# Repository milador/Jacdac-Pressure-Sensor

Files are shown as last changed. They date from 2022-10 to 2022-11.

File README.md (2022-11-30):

# Jacdac-Pressure-Sensor
A <a href="https://microsoft.github.io/jacdac-docs/">Jacdac</a> Pressure Sensor Module based on <a href="https://www.st.com/en/mems-and-sensors/lps33hw.html">LPS33HW</a> Absolute digital Pressure Sensor.

## Jacdac Dashboard: 

<p align="center">
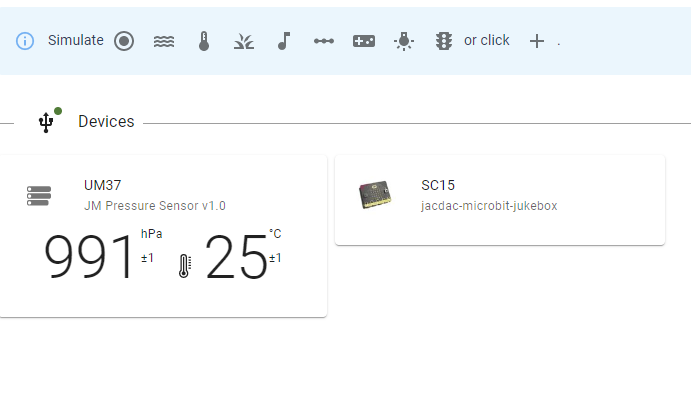
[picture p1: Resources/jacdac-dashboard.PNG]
Jacdac-Pressure-Sensor dashboard example

</p>

## Top View: 

<p align="center">
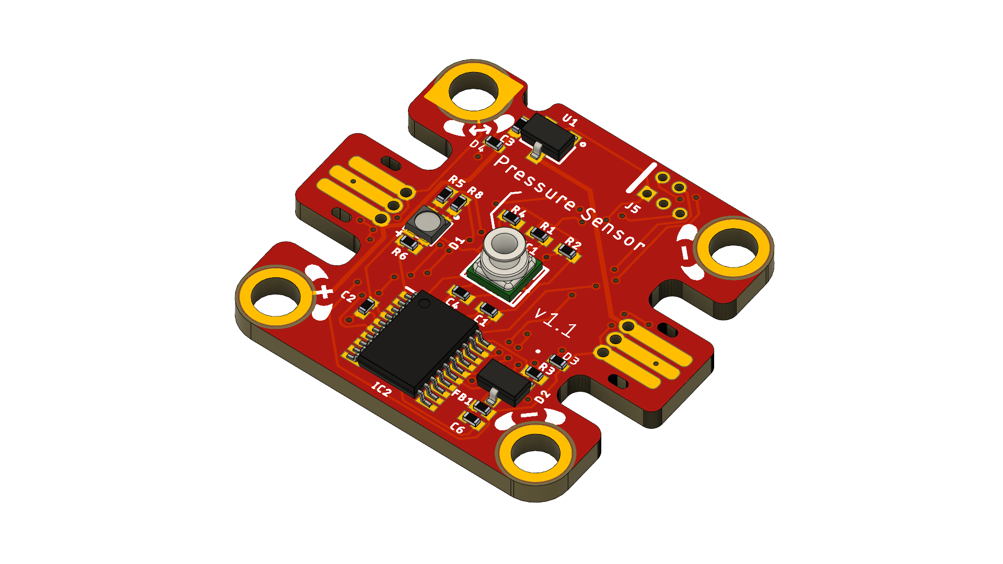
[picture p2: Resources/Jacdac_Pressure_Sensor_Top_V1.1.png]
Jacdac-Pressure-Sensor Top

</p>

## Bottom View:

<p align="center">
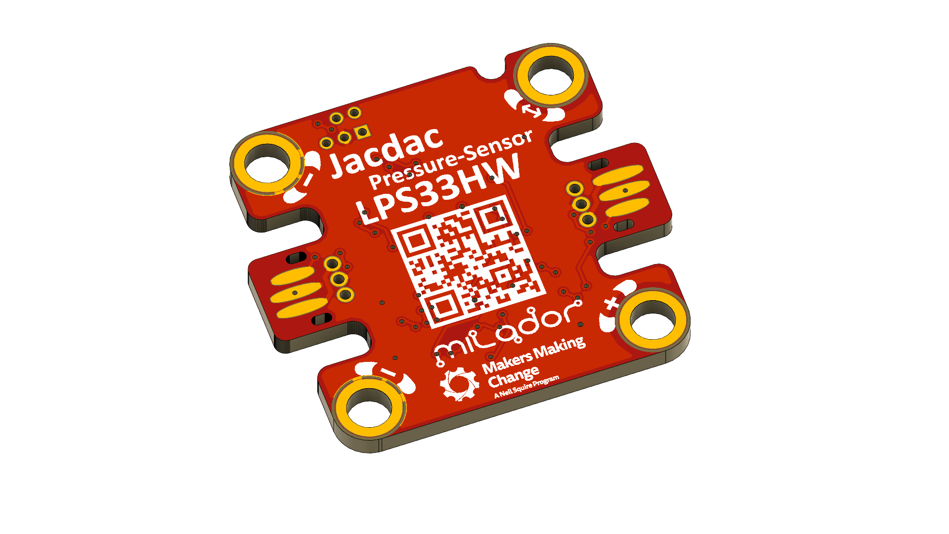
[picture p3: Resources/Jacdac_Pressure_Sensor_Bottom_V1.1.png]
Jacdac-Pressure-Sensor Bottom

</p>

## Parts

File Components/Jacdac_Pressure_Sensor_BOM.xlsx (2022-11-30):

Index | Quantity | Item | Value | Part Number | Manufacturer Part Number | Description | Unit Price (CAD) | Total Price (CAD) | Link
1 | 3 | R1,R2,R4 | 10K | C2902636 | ARG02BTC1002 | RES 10K OHM 0.1% 0402 | 0.0233 | 0.0699 | https://lcsc.com/product-detail/Chip-Resistor-Surface-Mount_Viking-Tech-ARG02BTC1002_C2902636.html
2 | 2 | R3,R5 | 220R | C317911 | AR02BTC2200 | RES 220 OHM 0.1% 0402 | 0.0272 | 0.0544 | https://lcsc.com/product-detail/Chip-Resistor-Surface-Mount_Viking-Tech-AR02BTC2200_C317911.html
3 | 1 | R6 | 470R | C482182 | CRCW0402470RFKED | RES 470 OHM 1% 0402 | 0.0394 | 0.0394 | https://lcsc.com/product-detail/Chip-Resistor-Surface-Mount_Vishay-Intertech-CRCW0402470RFKED_C482182.html
4 | 1 | R8 | 150R | C319855 | AR02BTC1500 | RES 150 OHM 0.1% 0402 | 0.032 | 0.032 | https://lcsc.com/product-detail/Chip-Resistor-Surface-Mount_Viking-Tech-AR02BTC1500_C319855.html
5 | 1 | IC1 | LPS33HWTR | C2760770 | LPS33HWTR | PRESSURE SENSOR | 10.89 | 10.89 | https://www.digikey.ca/en/products/detail/stmicroelectronics/LPS33HWTR/7348329 | https://lcsc.com/product-detail/Magnetic-Sensors_Infineon-Technologies-TLV493DA1B6HTSA2_C126688.html
6 | 1 | IC2 | STM32G030F6P6 | C724040 | STM32G030F6P6 | IC MCU 32BIT 32KB FLASH 20TSSOP | 0.98 | 0.98 | https://lcsc.com/product-detail/ST-Microelectronics_STMicroelectronics-STM32G030F6P6_C724040.html
7 | 1 | U1 | XC6206-3.3V | C2891841 | XC6206-3.3V | IC REG LINEAR 3.3V SOT-23-3L | 0.0614 | 0.0614 | https://lcsc.com/product-detail/Linear-Voltage-Regulators-LDO_YONGYUTAI-XC6206-3-3V_C2891841.html
8 | 2 | C1,C4 | 100nF | C361202 | C1005X5R1H104KT000F | 50V 100nF X5R ±10% 0402 | 0.0227 | 0.0454 | https://lcsc.com/product-detail/Multilayer-Ceramic-Capacitors-MLCC-SMD-SMT_TDK-C1005X5R1H104KT000F_C361202.html
9 | 2 | C2,C3 | 4.7uF | C342983 | C1005X5R1A475KTJ00E | 10V 4.7uF X5R ±10% 0402 | 0.0476 | 0.0952 | https://lcsc.com/product-detail/Multilayer-Ceramic-Capacitors-MLCC-SMD-SMT_TDK-C1005X5R1A475KTJ00E_C342983.html
10 | 1 | C6 | 33pF | C76905 | GJM1555C1H330GB01D | 50V 33pF C0G ±2% 0402 | 0.0335 | 0.0335 | https://lcsc.com/product-detail/Multilayer-Ceramic-Capacitors-MLCC-SMD-SMT_Murata-Electronics-GJM1555C1H330GB01D_C76905.html
11 | 1 | FB1 | 1kΩ @ 100MHz | C275423 | MMZ1005S102ET000 | FERRITE BEAD 250mA 1 1Ω 1kΩ@100MHz ±25% 0402 | 0.0308 | 0.0308 | https://lcsc.com/product-detail/Ferrite-Beads_TDK-MMZ1005S102ET000_C275423.html
12 | 1 | D1 | RGB LED | C108793 | FM-B2020RGBA-HG | LED RGB CHIP SMD | 0.0289 | 0.0289 | https://lcsc.com/product-detail/Light-Emitting-Diodes-LED_Foshan-NationStar-Optoelectronics-FM-B2020RGBA-HG_C108793.html
13 | 1 | D2 | BAT54S | C328578 | BAT54S,23 | DIODE ARRAY SCHOTTKY 30V SOT23 | 0.0245 | 0.0245 | https://lcsc.com/product-detail/Schottky-Barrier-Diodes-SBD_Foshan-Blue-Rocket-Elec-BAT54S_C328578.html
14 | 2 | D3,D4 | RCLAMP0521P | C2827711 | RCLAMP0521P | TVS DIODE 5VWM 25VC SLP1006P2 | 0.0445 | 0.089 | https://lcsc.com/product-detail/ESD-Protection-Devices_TECH-PUBLIC-RCLAMP0521P_C2827711.html
 |  |  |  |  |  |  | Total Price: | 12.4744

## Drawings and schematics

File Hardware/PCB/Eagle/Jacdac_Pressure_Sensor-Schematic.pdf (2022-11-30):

# 1k@100MHz VCC

# JD5V VCC

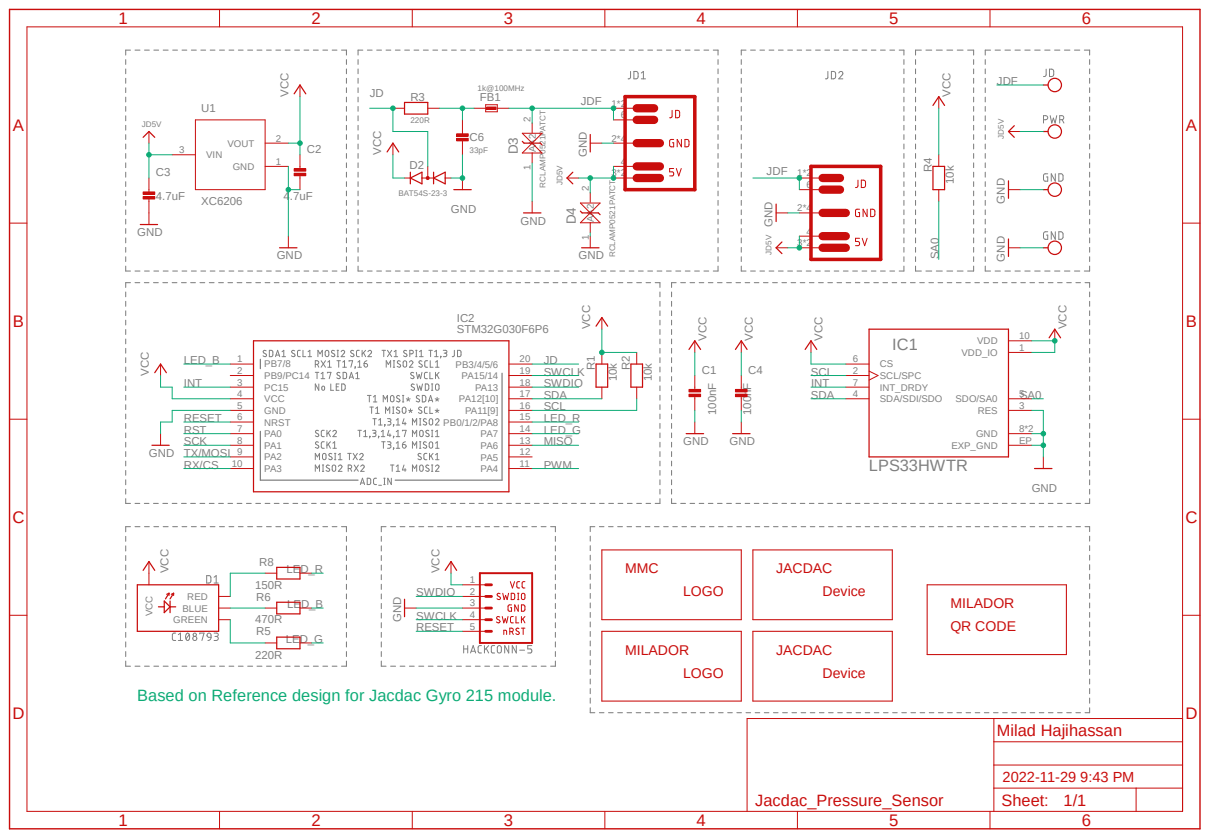
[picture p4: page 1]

Based on Reference design for Jacdac Gyro 215 module.

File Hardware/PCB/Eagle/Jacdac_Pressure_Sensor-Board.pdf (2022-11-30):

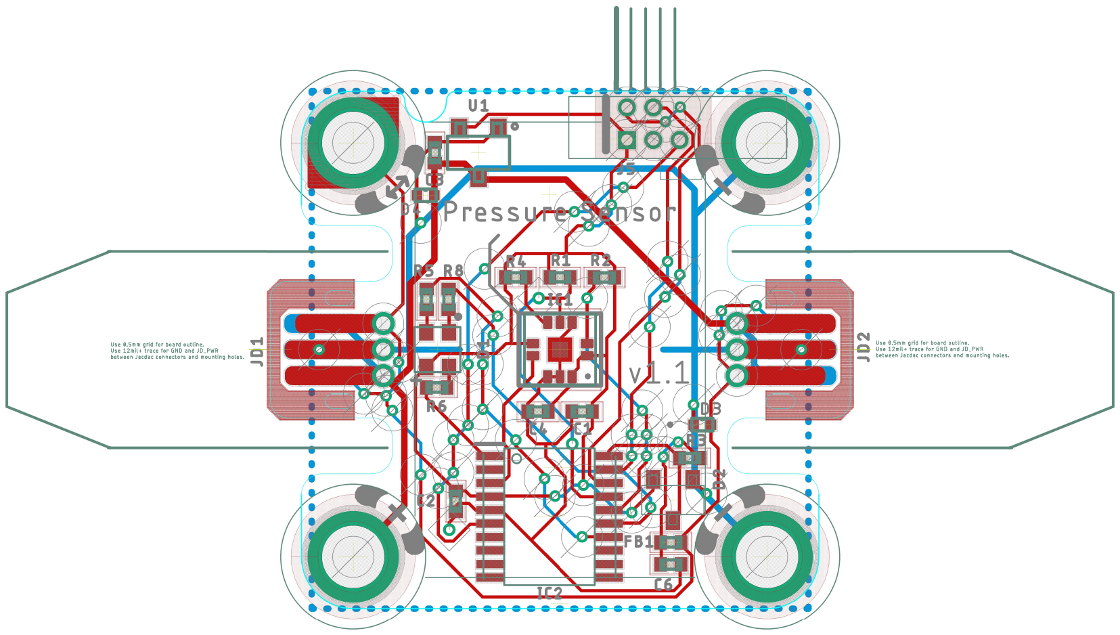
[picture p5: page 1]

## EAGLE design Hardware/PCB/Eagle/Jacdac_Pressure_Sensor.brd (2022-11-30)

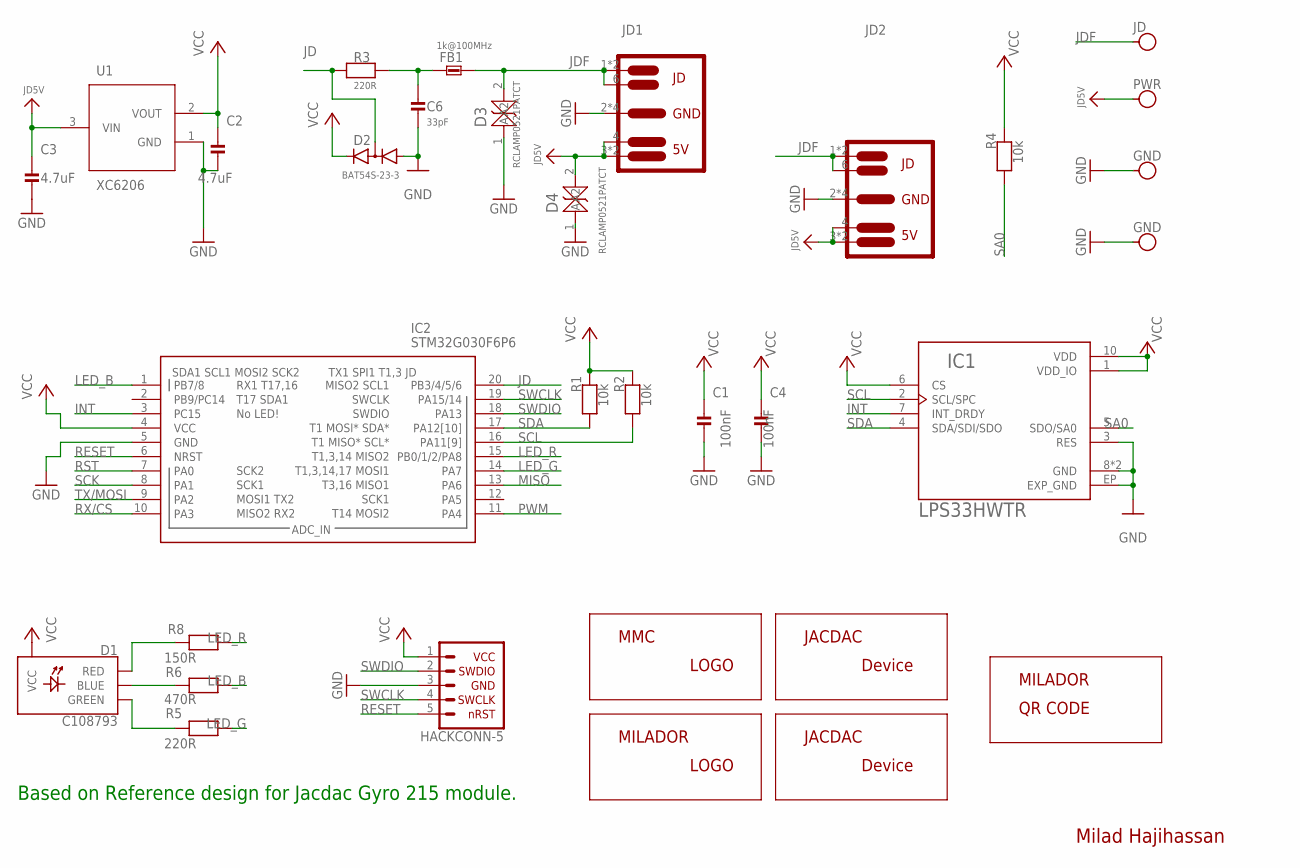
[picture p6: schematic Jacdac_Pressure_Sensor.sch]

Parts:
C1, C4: 100nF; 0402
C2, C3: 4.7uF; 0402
C6: 33pF; 0402
D1: C108793; LED-RGB-2121
D2: BAT54S-23-3; SOT23-3
D3, D4: RCLAMP0521PATCT; DIODE-ZENER-0402
FB1: 1k@100MHz; 0402
IC1: LPS33HWTR; PQFN60P330X330X290-11N
IC2: STM32G030F6P6; SOP65P640X120-20N
J1: JD; M3-HOLE-DATA
J2: PWR; M3-HOLE-PWR
J3, J4: GND; M3-HOLE-GND
J5: HACK-CONNECT-5; HC5-22-62
JD1, JD2: JACDAC-EDGE-OUTIE; JD-EDGE-OUTIE
LABEL_DEVICE: MILADOR-JACDAC-DEVICE-PS; JACDAC-PRESSURE-SENSOR
LABEL_LOGO1: MILADOR-LOGO-SM; MILADOR_LOGO2
LABEL_LOGO2: MMC_LOGO-XSM; MMC_X-SMALL_LOGO
LABEL_LPS33: MILADOR-JACDAC-DEVICE-LPS33HW; JACDAC-LPS33HW
LABEL_QRCODE: MILADOR-QR-CODE-JACDAC-GITHUB-PS; MILADOR_QR_JACDAC_PS
R1, R2, R4: 10k; 0402
R3, R5: 220R; 0402
R6: 470R; 0402
R8: 150R; 0402
U1: XC6206; SOT23-3-W

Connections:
GND: C1.2, C2.2, C3.2, C4.2, C6.2, D2.1 (A1), D3.1 (A), D4.1 (A), IC1.3 (RES), IC1.8 (GND), IC1.9 (GND), IC1.EP (EXP_GND), IC2.5 (GND), J3.H, J4.H, J5.3 (GND), JD1.2 (1), JD1.5 (1), JD1.P$2 (1), JD1.P$4 (1), JD2.2 (1), JD2.5 (1), JD2.P$2 (1), JD2.P$4 (1), U1.1 (GND)
INT: IC1.7 (INT_DRDY), IC2.3 (PC15)
JD: D2.3 (C1A2), IC2.20 (PB3/4/5/6), R3.1
JD5V: C3.1, D4.2 (A2), J2.H, JD1.3, JD1.4, JD1.P$1 (3), JD2.3, JD2.4, JD2.P$1 (3), U1.3 (VIN)
JDF: D3.2 (A2), FB1.2, J1.H, JD1.1 (2), JD1.6, JD1.P$3 (2), JD2.1 (2), JD2.6, JD2.P$3 (2)
LED_B: IC2.1 (PB7/8), R6.1
LED_G: IC2.14 (PA7), R5.1
LED_R: IC2.15 (PB0/1/2/PA8), R8.1
MISO: IC2.13 (PA6)
unnamed: C6.1, FB1.1, R3.2
unnamed: D1.B- (BLUE), R6.2
unnamed: D1.R- (RED), R8.2
unnamed: D1.G- (GREEN), R5.2
PWM: IC2.11 (PA4)
RESET: IC2.6 (NRST), J5.5 (NRST)
RST: IC2.7 (PA0)
RX/CS: IC2.10 (PA3)
SA0: IC1.5 (SDO/SA0), R4.1
SCK: IC2.8 (PA1)
SCL: IC1.2 (SCL/SPC), IC2.16 (PA11[9]), R2.1
SDA: IC1.4 (SDA/SDI/SDO), IC2.17 (PA12[10]), R1.1
SWCLK: IC2.19 (PA15/14), J5.4 (SWCLK)
SWDIO: IC2.18 (PA13), J5.2 (SWDIO)
TX/MOSI: IC2.9 (PA2)
VCC: C1.1, C2.1, C4.1, D1.PLUS (VCC), D2.2 (C2), IC1.1 (VDD_IO), IC1.6 (CS), IC1.10 (VDD), IC2.4 (VCC), J5.1 (VCC), R1.2, R2.2, R4.2, U1.2 (VOUT)

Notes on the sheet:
Based on Reference design for Jacdac Gyro 215 module.
Milad Hajihassan

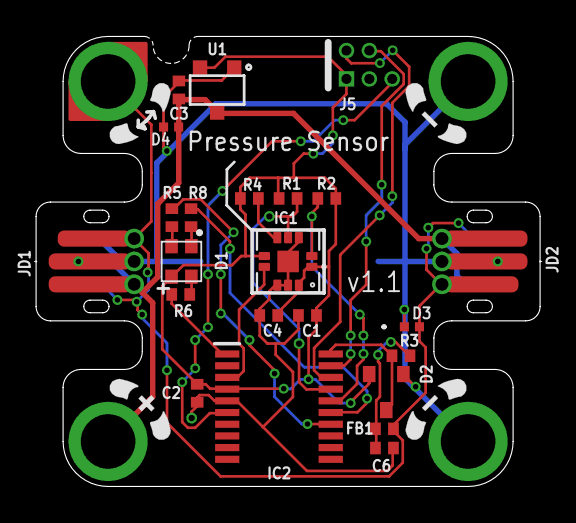
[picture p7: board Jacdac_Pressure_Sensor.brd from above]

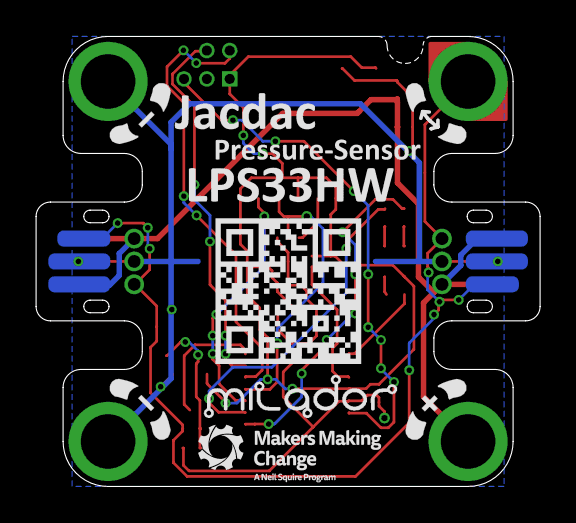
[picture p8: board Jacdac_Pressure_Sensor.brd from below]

Board: 2 copper layers, 28.0 x 25.0 mm, 32 parts (5 on the bottom side), 19 nets.

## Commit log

2021-09-15 Added Initial design
    [Jacdac_Pressure_Sensor.brd, Jacdac_Pressure_Sensor.sch, Jacdac_Pressure_Sensor_Maker.brd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]
2021-09-17 Updated PCB files
    [Jacdac_Pressure_Sensor.brd, Jacdac_Pressure_Sensor.sch, Jacdac_Pressure_Sensor_BOM.xlsx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]
2021-09-18 Updated Maker version
    [Jacdac_Pressure_Sensor.brd, Jacdac_Pressure_Sensor_Maker.brd, Jacdac_Pressure_Sensor_Maker_BOM.xlsx]
2022-02-20 Updated design
    Use I2C instead of SPI
    [Jacdac_Pressure_Sensor.brd, Jacdac_Pressure_Sensor.sch, Jacdac_Pressure_Sensor_Maker.brd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]
2022-02-28 Updated files
    [Jacdac_Pressure_Sensor_Maker.brd]
2022-03-20 Corrected Capacitor values
    [Jacdac_Pressure_Sensor.brd, Jacdac_Pressure_Sensor.sch, Jacdac_Pressure_Sensor_BOM.xlsx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]
2022-03-27 Updated main design
    Centering the sensor
    [Jacdac_Pressure_Sensor.brd, Jacdac_Pressure_Sensor.sch, Jacdac_Pressure_Sensor_BOM.xlsx]
2022-03-29 Updated PCB
    [Jacdac_Pressure_Sensor.brd, Jacdac_Pressure_Sensor.sch]
2022-03-30 Added Additional ground via
    [Jacdac_Pressure_Sensor.brd]
2022-06-23 Updated design : Centered Pressure Sensor
    [Jacdac_Pressure_Sensor.brd, Jacdac_Pressure_Sensor.sch, Jacdac_Pressure_Sensor_Maker.brd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]
2022-06-23 Updated gerber files
2022-07-06 Added version 1.0
    [Jacdac_Pressure_Sensor.brd, Jacdac_Pressure_Sensor.sch, Jacdac_Pressure_Sensor_BOM.xlsx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]
2022-07-07 Updated BOM
    [Jacdac_Pressure_Sensor_BOM.xlsx, Jacdac_Pressure_Sensor_Maker_BOM.xlsx]
2022-07-09 Updated RevB
    [Jacdac_Pressure_Sensor-RevA-Maker.brd, Jacdac_Pressure_Sensor-RevA-Maker.sch, Jacdac_Pressure_Sensor-RevA.brd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]
2022-07-13 Updated RevB design to match pinouts of other Jacdac modules
    [Jacdac_Pressure_Sensor-RevB.brd]
2022-07-14 Updated board.pdf
2022-07-14 Updated components value
    [Jacdac_Pressure_Sensor-RevB.brd, Jacdac_Pressure_Sensor-RevB.sch]
2022-08-10 Updated BOM for SMT
    [Jacdac_Pressure_Sensor-RevB.sch, Jacdac_Pressure_Sensor_BOM.xlsx, Jacdac_Pressure_Sensor_RevB_BOM.xlsx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]
2022-10-15 Updated design : Added CS trace
    [Jacdac_Pressure_Sensor-RevB.brd, Jacdac_Pressure_Sensor-RevB.sch]
2022-10-15 Updated CPL
    [Jacdac_Pressure_Sensor-RevB_cpl.csv, Jacdac_Pressure_Sensor-RevB_top_cpl.csv]
2022-10-15 Updated revision A
    [Jacdac_Pressure_Sensor-RevA-Maker.brd, Jacdac_Pressure_Sensor-RevA-Maker.sch, Jacdac_Pressure_Sensor-RevA.brd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]
2022-10-20 Updated RevB : Added Pull-Up to SA0
    [Jacdac_Pressure_Sensor-RevB.brd, Jacdac_Pressure_Sensor-RevB.sch]
2022-10-20 Added RevC : Added ESD protection diodes
    [Jacdac_Pressure_Sensor-RevC.brd, Jacdac_Pressure_Sensor-RevC.sch]
2022-11-30 Added gerber and cpl files
    [Jacdac_Pressure_Sensor-RevC_bottom_cpl.csv, Jacdac_Pressure_Sensor-RevC_cpl.csv, Jacdac_Pressure_Sensor-RevC_top_cpl.csv]
2022-11-30 Added RevC BOM
    [Jacdac_Pressure_Sensor_RevC_BOM.xlsx]
2022-11-30 Updated documentation and files to freeze the design V1.1
    [Jacdac_Pressure_Sensor-RevA-Maker.brd, Jacdac_Pressure_Sensor-RevA-Maker.sch, Jacdac_Pressure_Sensor-RevA.brd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]

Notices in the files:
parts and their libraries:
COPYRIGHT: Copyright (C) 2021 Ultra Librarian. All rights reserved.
